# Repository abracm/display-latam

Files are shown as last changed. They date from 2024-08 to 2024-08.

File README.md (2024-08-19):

# display-latam
ESP32-based project to make a display for speedcubing timers.

We seek to create an alternative to commercially available displays which is cheaper, lighter,open-source, repairable, and sustainable.

## How to contribute

Take a look at the open issues on the repository to see how you can contribute. Open an issue for a request or suggestion. You can also send an email for contato@abracm.org.br for enquries, contributions, feedback, etc.

The language of the project is English to make it more accesible worldwide.

Please stick to the following best practices when contributing to this project:
- Open a new branch and a pull request (PR) whenever you want to change the code or documentation
- Make sure to provide enough details about the changes in your PR so other contributors can easily understand them  
- Always wait for at least one approving review before merging the PR

Currently, the code is functional, but the documentation needs work, which makes it hard for communities to build their own version. The work plan is on the short medium term is:
1. gather ideas and contributions for an Alpha release
2. incorporate pull requests, contributions which are a short term priority
3. prepare documentation, tutorials for the release of the Alpha version 
4. release the Alpha version, make easily available for communities to build and test out - can we do it by the end of August/start of September?
5. work on improvements to the Alpha version, receive feedback from users
6. create hardware specifications for a 1.0 version release (make hardware investments future proof)
7. release 1.0 version of project, make sure future code updates are backwards compatible with the hardware

## Features

TODO 
add video demo

## Libraries setup
From Libs.zip, extrac Libs folder and copy it's contents to your Arduino/Libraries directory.

## Software Installation guide
Software Installation guide:

1. Install the Arduino IDE software from https://www.arduino.cc/en/software 
2. It should create a folder named “Arduino” in Documents, you want to create 2 folders, “display-latam”, and “Libraries”.
3. Download the Libs.zip file from the GitHub, extract the zip file, and then place all of the folders in the zip file to the “Libraries” folder.

4. Place the “display-latam.ino”, “xantofont.cpp”, and “xantofont.h” files in the “display_latam folder.

5. Click on the display-latam.ino file to open it up in Arduino IDE. 
6. Connect your board to your computer with USB, the official Arduino website has more detailed instructions on this. I actually had a lot of trouble with this initially, my solution was to just try every USB port until one worked. https://support.arduino.cc/hc/en-us/articles/4406856349970-Select-board-and-port-in-Arduino-IDE 
7. Press the upload button and wait for it to upload. You also need to use a USB cable that is capable of transmitting data (some USB cables have power only) or it will not be able to upload. 



8. It should finish uploading successfully and the console should look like this when it is finished. The display should be ready for usage now.


## installation, how to build

TODO 

Draft preview of the project (using the acrylic covers)
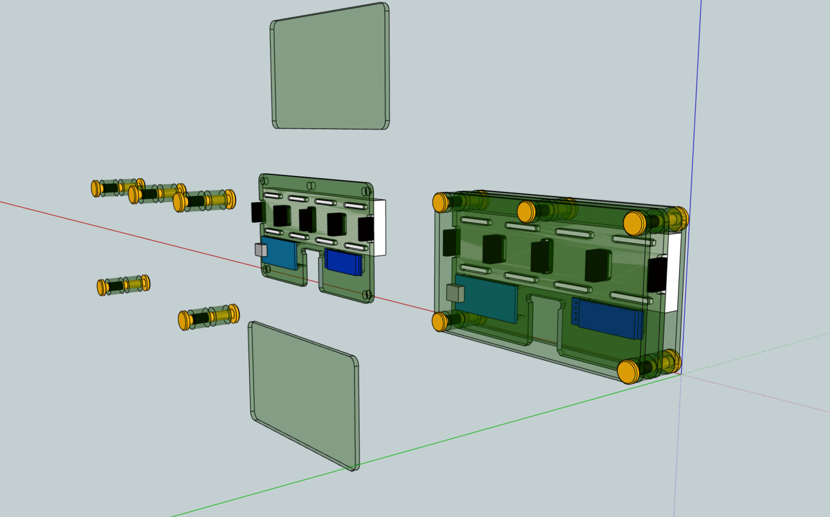
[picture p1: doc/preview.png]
draft_preview


Schematics for the ESP32 C3 mini are as follows:

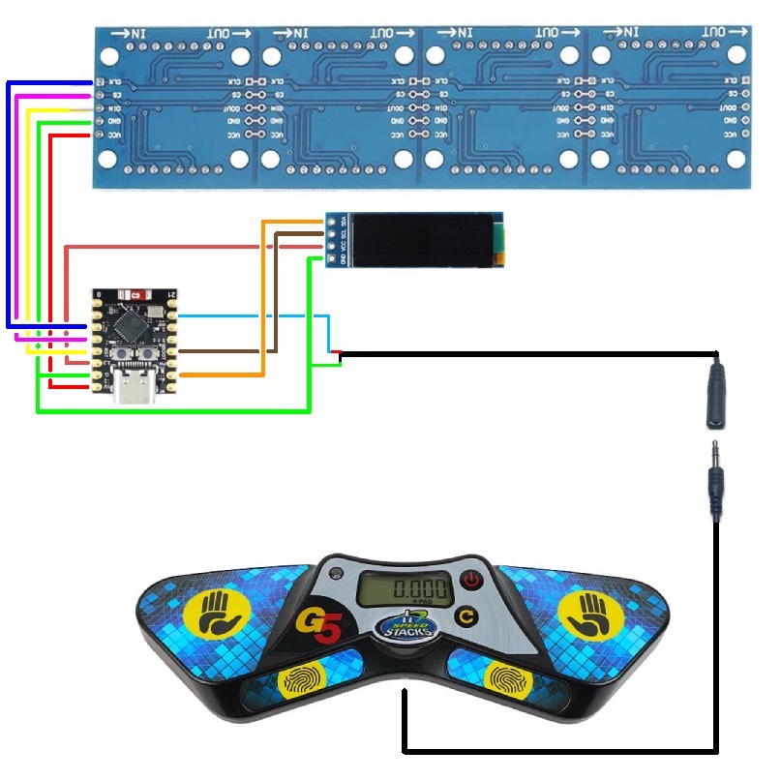
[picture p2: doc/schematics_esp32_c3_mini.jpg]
schematics_esp32_c3_mini


Schematics for the ESP32 S2 are also available at `doc/schematics_esp32_s2.jpg`
### Parts list

- ESP32 C3 mini (you might be able to use other ESP32s or Arduinos with code changes, testing needed)
- 4 in 1 MAX7219 LED display matrix
- 0.91” OLED display
- 3.5mm female jack to bare wire with 2 pole
- 3.5mm to 2.5mm data cable (to connect to the timer)
- wires and solder

Two alternatives for encasing the hardware: 

| Materials/type | Details |
| --- | --- |
| <ul><li>3mm polycarbonate sheet</li><li>Chicago screws that are 25mm long and 5mm in diameter</li><li>Spacers of 5mm in diameter with a length according to the LED matrix you have. If the display has sockets, you need spacers four 7mm long spacers and four 10mm long ones. If the display is soldered, you need eight spacers with a length of 8.5mm.</li><li>tint for contrast</li></ul> | cutout for CNC available on `doc/acrylic-cover.skp`, see `doc/prototype_demo.skp` for demo on how to build |
| 3D printed case | draft design available on `doc/draft_case.stl` (WIP) |

For power, you could use:
- Standard USBC 5v chargers plugged to a power source
- Power banks, e.g. made using 18650 batteries and a battery case (this is usually cheaper than buying a commercial power bank)

For the display stand, you could use the 3D-printed stand available on `doc/stand.stl`.

Current estimates for the cost of the materials for a display are of around USD ~20 (buying supplies off China e.g. Aliexpress).

## Contributors

We are specially greatful to Fabio Seiji Massui [2013MASS01](https://www.worldcubeassociation.org/persons/2013MASS01) for kicking off this project and inspiring us to pursue the goal of developing an open-source and cheap alternative to commercial displays.

Other contributors include:
- jayanth-rajakumar: Original [ledmat](https://github.com/jayanth-rajakumar/ledmat) project
- Cady Shields: 3D-printed display stand design
- Alex Maass: 3D-printed case design

## Speedstacks timer signal protocol

The Speedstacks timers send a digital audio signal thorugh the data port ([example](https://imgur.com/mRPrlxn)). This is a guide how on to interpret the signal.

The timer sends the signal with a fixed rate of 1200 bits per second (check if this is correct and consistent across all timer generations). It sends a packet that are 90 or 100 bytes long to convey a single time to be displayed.

### Idle values

The bitstream user a standard idle value (0 or 1) to inform when a byte or a packet ended. The idle value varies across timer generations (see section below on timer generations).

Each byte is proceeded by a non-idle value, to show that the byte has begun, and followed by an idle value, to show that it has ended.

Gen 3
*example of a Gen 3 timer bitstream- the idle value is 1*

Gen 4
*example of a Gen 4 timer bitstream- the idle value is 0*

Each packet is separated by an unspecificed number of idle values (check if we can tell an exact amount and if it is consistent across timers). Therefore, to check if a packet has ended, you just need to check if you can read ten or more equal values in a row, as that couldn't happen if a byte was being transmitted.

### Packets

A time to be displayed is sent as a packet that can be 9 or 10 bytes long. The lenght of the packet is determined by the timer generation (see section below on timer generations).

Because of the non-idle value and idle value that go before and after each byte, the bytes take 10 bits to be transmitted, and the packet lenghts are therefore 90 or 100 bits.

Here is an example of a full packet extracted from a Gen 3 timer that will use to break down what each byte means. **TODO**

Notice that this packet it 10 bytes long and uses 1 as its idle value.

These are what each byte consists of:

#### byte 1: state of the timer

The first byte is an ASCII code for one of the following letters, which represent the state the timer is in:

- "L" (Left hand on timer)
- "R" (Right hand on timer)
- "C" (Both hands on timer)
- "A" (Ready to start)
- "I" (Reset)
- "S" (Stopped)
- " " (Running and no hands on sensor)

#### byte 2-6 or 2-7: time itself

These are the bytes that convey the time information. Byte 7 may or may not be a part of this depending on the timer generation (see section below on timer generations).

Here is the breakdown on byte-by-byte:
- 2: minutes
- 3: tens of seconds
- 4: units of seconds
- 5: tenths of a second
- 6: hundreths of a second
- 7 (if in use): thousands of a second (check - if 7th byte no used to convey time information, does timer simply not transmit thousands of a second?)

The byte represents the ASCII code for the digit, which is the digit + 48

#### 3rd to last byte: checksum

This byte is a checksum of the previous bytes (2-6 or 2-7), to ensure the reading is correct.

It it the sum of the values (not the ASCII codes) of all digits + 64.

#### 2nd to last and last bytes: unnecessary line breaks?

These bytes are the ASCII codes for \n (newline) and \r (carriage return). Is this just useless?

### Processing a byte

After reading the 10 bits necessary for a byte (non-idle value + byte + idle value), you must first discard the 1st and the last bits of the byte.

Then, you must place the bits in reverse order. E.g. (11001001 becomes 10010011)

Finally, the bits must be inverted to arrive at the final byte (10010011 becomes 01101100). *do timers with a 0 idle value also need to be inverted?*

### Example of interpreting a packet from start to finish

WIP

### Speedstacks timer generations

#### Generation 3
Gen 3
- Packet length: 10 bytes
- Idle value: 1

#### Generation 4
Gen 4
- Packet length: 9 bytes (dobule check)
- Idle value: 0 (double check)

#### Generation 5
Gen 5
- Packet length: need to check
- Idle value: 1 (double check)

*can we easily support other non-speedstacks timers? testing needed*

### Useful sources

- Odder's Stacktimer Signal Processor [link](https://github.com/Kubiverse/StackmatSignalProcessor): reference on how to process the stackmat signal bitstream (for Gen 4 timers)
- JFly's [explanation](https://www.jflei.com/2014/08/21/dialup-stackmat/) on the speedstacks timer signal and reading it in a phone
- freundTech's [explanation](https://old.reddit.com/r/Cubers/comments/64czya/wip_stackmat_timer_support_for_twistytimer_app/dg19s4y/) on what the speedstacks timer signal bitstream is composed of
- Dan Smith [testing](https://youtu.be/1QEm99bT8WQ?si=v6V7CJI6A0WZBTTA) what causes reset issues in Gen 5 timers
- Coding [experiments](https://forum.arduino.cc/t/display-for-stackmat-timer/946502) on forum
- [Wiring](https://lastminuteengineers.com/max7219-dot-matrix-arduino-tutorial/) a MAX7219 LED Dot Matrix
- Getting [started](https://www.circuitgeeks.com/arduino-max7219-led-matrix-display/) with MD Parola
- Old stackmat display [project](https://web.archive.org/web/20100820185842/http://hackvalue.de:80/hv_atmel_stackmat)

#### Migrating an Arduino board to a standalone microcontroller on a breadboard

- https://docs.arduino.cc/built-in-examples/arduino-isp/ArduinoToBreadboard
- https://www.martyncurrey.com/arduino-atmega-328p-fuse-settings/
- https://www.instructables.com/Configure-Arduino-IDE-for-Atmega-328P-to-Use-8MHz-/
- https://www.instructables.com/USBASP-Bootloading-a-ATMega328p-with-a-8mhZ-intern/

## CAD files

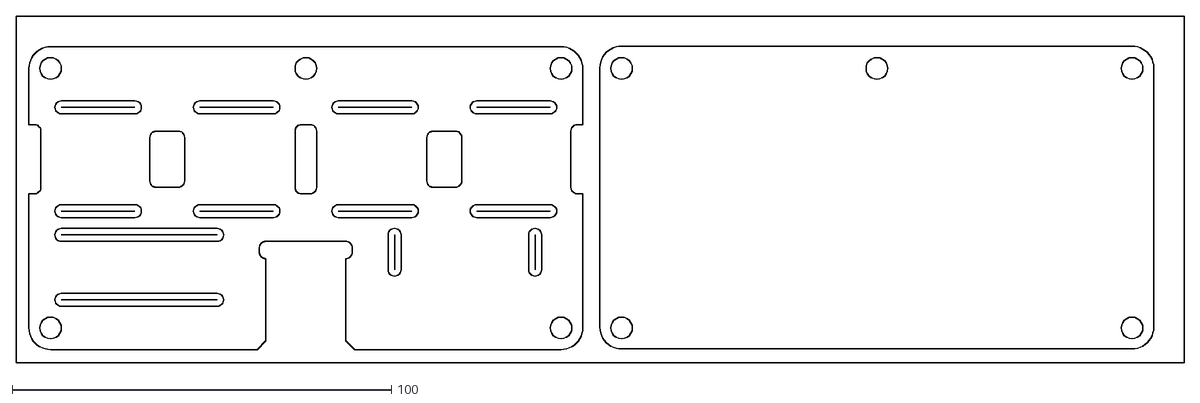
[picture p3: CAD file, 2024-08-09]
doc/AcrylicCover.dxf
308.2 x 91.3

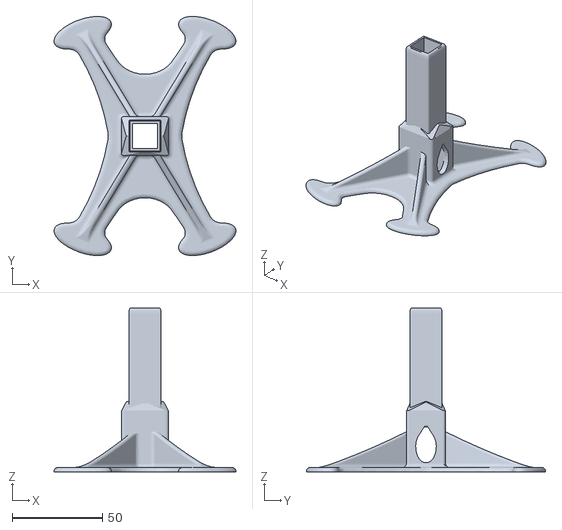
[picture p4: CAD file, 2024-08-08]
doc/stand.stl
101.1 x 132.8 x 91.0

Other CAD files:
doc/acrylic-cover.skp
doc/prototype_demo.skp

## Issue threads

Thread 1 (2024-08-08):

Decide on a better name for the project

mirandapedro, 2024-08-08:
We want a better name that:
- is more unique, marketable
- reflects the Latin American identity and origin
- is preferably in Portuguese and Spanish

Suggestions we have received so far:
- Algo en español/portugués podría ser interesante para indicar el origen
- "Números" quizás jajaj o alguna cosa así que sea igual en ambos idiomas
- display purtanol
- all i can think that is common for all latin america is the passion for futebol

SeijiMassui, 2024-08-21:
My suggestion is Megatherium

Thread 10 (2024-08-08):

Improve installation guide and build guide

mirandapedro, 2024-08-08:
Ideally, we'd have both the usual technical documentation, but also a very basic how-to guide (if possible, even a video), teaching how to build the project, so that it is as accessible as possible for communities, regardless of their level of technical expertise.

mirandapedro, 2024-08-09:
Should we recommend a specific version of an ESP32/arduino as a default for the project or can we make the project and code version neutral?

alexmaasswca, 2024-08-09:
I think we should stick with the C3because the acrylic case is designed for that, the boards seem to be roughly all about a few dollars on aliexpress for me so I don't see any major price differences there.

I think we should try to get the C3 working first and perfected and then add in support for different boards.

mirandapedro, 2024-08-09:
Just to note the specific version of the ESP32 C3 mini we used in our first batch of display is the ESP32-C3FH4. I don't believe any of the differences between the versions of the ESP32 C3 mini impact our project, but it's worth noting for future testing and documentation.

soyrandom1, 2024-08-17:
Code should work with most arduino or esp versions.
In some cases used pins might change depending on the board used, but it's extremely easy to modify in code.

mirandapedro, 2024-08-17:
@soyrandom1 do you believe the code is ready for an Alpha release (after merging your PR)?

If so, the only thing holding us back would be the documentation/tutorial.

My hope was to have an alpha version ready as soon as possible to make the first prototype available to interested communities. Also, a first release might also attract the interest of additional contributors.

soyrandom1, 2024-08-19:
Solved #19

Closed 2024-08-19.

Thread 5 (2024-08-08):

Prevent the Gen 5 timer from switching on and off the time displayed after an attempt

mirandapedro, 2024-08-08:
- the Gen 5 timer has an annoying feature that, when in 2-pad mode, it switches off and on three times after the timer is stopped, which is reproduced on the display, we should try to avoid this behaviour

I have the impression that the current version of the code already prevents this, we need to check

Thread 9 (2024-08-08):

Improve the schematics in the README

mirandapedro, 2024-08-08:

mirandapedro, 2024-08-17:
Fixed by 3844d9cc04f159badeeef381240765e3ebc82951

Closed 2024-08-17.

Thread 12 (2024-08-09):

Libraries missing

alexmaasswca, 2024-08-09:
I had a lot of trouble installing arduino libraries with the jayanth github. I think it is problematic to just simply say "download this library from this other github" because the libraries can change, this actually led to an issue with jayanth's project because he had to reupload an older version of the libraries so it would work for other people.

This is the same case here, for example running the program gets me this error that simply says that the Adafruit.h library is not there so I think it would be best to have a UsedLibraries folder on the github here and place every library needed in that folder, so it'll always work and be very easy to download multiple libraries without having to worry about the libraries being updated.

I'll be down to write a guide on how to install the whole thing once the libraries are posted in a folder here.

soyrandom1, 2024-08-17:
Uploaded all libraries [here](https://github.com/abracm/display-latam/blob/main/Libs.zip)

Closed 2024-08-17.

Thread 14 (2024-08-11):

Alternative to the 3D-printed stand

mirandapedro, 2024-08-11:
Can we think of a better alternative to the 3D-printed stand? Is it needed?

Fabio Seiji experimented with aluminium extrusions (see below). Alex Maass also suggested using them.

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

This contraption would attach vertically to a table. The yellow parts were supposed to act as clamps to hold the stand up. In practice, it didn't work very well.

alexmaasswca, 2024-08-13:
https://www.aliexpress.us/item/3256807085443535.html this looks decent, I just ordered one to test out

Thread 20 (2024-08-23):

LED Matrix increases in brightness several seconds after timer with 0.00 is turned off

alexmaasswca, 2024-08-23:
The LED Matrix increases in brightness several seconds after timer with 0.00 is turned off, I can replicate with a video if necessary. This is a pretty minor issue, I don't see the harm in this besides unnecessary battery usage.

soyrandom1, 2024-08-23:
Fixed here https://github.com/abracm/display-latam/pull/21

Closed 2024-08-23.

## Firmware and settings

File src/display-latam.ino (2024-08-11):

#include <Arduino.h>

//OLED Display Libraries
#include <Adafruit_GFX.h>
#include <Adafruit_SSD1306.h>

//Libraries for LED Matrix
#include <MD_Parola.h>
#include <MD_MAX72xx.h>

//Communication Libaries
#include <SPI.h>
#include <Wire.h>
#include <SoftwareSerial.h>

//StackmatTimer Library
#include <StackmatTimer.h>

//OLED Font
#include <Fonts/FreeSans18pt7b.h>

//Define LED Matrix and SPI communication ports/pins
#define MAX_DEVICES 4
#define CLK_PIN 2
#define DATA_PIN 4
#define CS_PIN 3
#define HARDWARE_TYPE MD_MAX72XX::FC16_HW

//Define I2C ports/pins for OLED communication
#define SDA_PIN 6
#define SCL_PIN 8

#define SCREEN_WIDTH 128  // OLED display length in pixels
#define SCREEN_HEIGHT 32  // OLED display height in pixels

#define OLED_RESET -1
#define OLED_ADDRESS 0x3c

//#define led_ON 15 // S2 Mini onboard LED

MD_Parola P = MD_Parola(HARDWARE_TYPE, DATA_PIN, CLK_PIN, CS_PIN, MAX_DEVICES);

Adafruit_SSD1306 oled(SCREEN_WIDTH, SCREEN_HEIGHT, &Wire, OLED_RESET);

//Font for LED Matrix
MD_MAX72XX::fontType_t xantofont[] PROGMEM = {
  0,                              // 0 - 'Empty Cell'
  5, 62, 91, 79, 91, 62,          // 1 - 'Sad Smiley'
  5, 62, 107, 79, 107, 62,        // 2 - 'Happy Smiley'
  5, 28, 62, 124, 62, 28,         // 3 - 'Heart'
  5, 24, 60, 126, 60, 24,         // 4 - 'Diamond'
  5, 28, 87, 125, 87, 28,         // 5 - 'Clubs'
  5, 28, 94, 127, 94, 28,         // 6 - 'Spades'
  4, 0, 24, 60, 24,               // 7 - 'Bullet Point'
  5, 255, 231, 195, 231, 255,     // 8 - 'Rev Bullet Point'
  4, 0, 24, 36, 24,               // 9 - 'Hollow Bullet Point'
  5, 255, 231, 219, 231, 255,     // 10 - 'Rev Hollow BP'
  5, 48, 72, 58, 6, 14,           // 11 - 'Male'
  5, 38, 41, 121, 41, 38,         // 12 - 'Female'
  5, 64, 127, 5, 5, 7,            // 13 - 'Music Note 1'
  5, 64, 127, 5, 37, 63,          // 14 - 'Music Note 2'
  5, 90, 60, 231, 60, 90,         // 15 - 'Snowflake'
  5, 127, 62, 28, 28, 8,          // 16 - 'Right Pointer'
  5, 8, 28, 28, 62, 127,          // 17 - 'Left Pointer'
  5, 20, 34, 127, 34, 20,         // 18 - 'UpDown Arrows'
  5, 95, 95, 0, 95, 95,           // 19 - 'Double Exclamation'
  5, 6, 9, 127, 1, 127,           // 20 - 'Paragraph Mark'
  4, 102, 137, 149, 106,          // 21 - 'Section Mark'
  5, 96, 96, 96, 96, 96,          // 22 - 'Double Underline'
  5, 148, 162, 255, 162, 148,     // 23 - 'UpDown Underlined'
  5, 8, 4, 126, 4, 8,             // 24 - 'Up Arrow'
  5, 16, 32, 126, 32, 16,         // 25 - 'Down Arrow'
  5, 8, 8, 42, 28, 8,             // 26 - 'Right Arrow'
  5, 8, 28, 42, 8, 8,             // 27 - 'Left Arrow'
  5, 30, 16, 16, 16, 16,          // 28 - 'Angled'
  5, 12, 30, 12, 30, 12,          // 29 - 'Squashed #'
  5, 48, 56, 62, 56, 48,          // 30 - 'Up Pointer'
  5, 6, 14, 62, 14, 6,            // 31 - 'Down Pointer'
  2, 0, 0,                        // 32 - 'Space'
  1, 95,                          // 33 - '!'
  3, 7, 0, 7,                     // 34 - '"'
  5, 20, 127, 20, 127, 20,        // 35 - '#'
  5, 36, 42, 127, 42, 18,         // 36 - '$'
  5, 35, 19, 8, 100, 98,          // 37 - '%'
  5, 54, 73, 86, 32, 80,          // 38 - '&'
  3, 8, 7, 3,                     // 39 - '''
  3, 28, 34, 65,                  // 40 - '('
  3, 65, 34, 28,                  // 41 - ')'
  5, 42, 28, 127, 28, 42,         // 42 - '*'
  5, 8, 8, 62, 8, 8,              // 43 - '+'
  3, 128, 112, 48,                // 44 - ','
  6, 0, 8, 8, 8, 8, 8,            // 45 - '-'
  1, 64,                          // 2, 964, 96,    // 46 - '.'
  5, 32, 16, 8, 4, 2,             // 47 - '/'
  5, 126, 129, 129, 126, 0,       // 6, 0, 126, 129, 129, 129, 126,    // 48 - '0'
  5, 130, 255, 128, 0, 0,         // 6, 0, 0, 130, 255, 128,0,   // 49 - '1'
  5, 226, 145, 137, 134, 0,       // 6, 0, 130, 193, 161, 145, 142,    // 50 - '2'
  5, 66, 137, 137, 118, 0,        // 6, 0, 66, 129, 137, 137, 118,   // 51 - '3'
  5, 24, 20, 18, 255, 0,          // 6, 0, 48, 40, 36, 34, 255,    // 52 - '4'
  5, 79, 137, 137, 113, 0,        // 6, 0, 79, 137, 137, 137, 113,   // 53 - '5'
  5, 126, 137, 137, 114, 0,       // 6, 0, 126, 137, 137, 137, 114,    // 54 - '6'
  5, 225, 17, 9, 7, 0,            // 6, 0, 1, 225, 17, 9, 7,   // 55 - '7'
  5, 118, 137, 137, 118, 0,       // 6, 0, 118, 137, 137, 137, 118,    // 56 - '8'
  5, 78, 145, 145, 126, 0,        // 6, 0, 78, 145, 145, 145, 126,   // 57 - '9'
  1, 68,                          // 1, 36,    // 58 - ':'
  2, 128, 104,                    // 59 - ';'
  4, 8, 20, 34, 65,               // 60 - '<'
  5, 20, 20, 20, 20, 20,          // 61 - '='
  4, 65, 34, 20, 8,               // 62 - '>'
  5, 2, 1, 89, 9, 6,              // 63 - '?'
  5, 62, 65, 93, 89, 78,          // 64 - '@'
  5, 124, 18, 17, 18, 124,        // 65 - 'A'
  5, 127, 73, 73, 73, 54,         // 66 - 'B'
  5, 62, 65, 65, 65, 34,          // 67 - 'C'
  5, 127, 65, 65, 65, 62,         // 68 - 'D'
  5, 127, 73, 73, 73, 65,         // 69 - 'E'
  5, 127, 9, 9, 9, 1,             // 70 - 'F'
  5, 62, 65, 65, 81, 115,         // 71 - 'G'
  5, 127, 8, 8, 8, 127,           // 72 - 'H'
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
  5, 60, 38, 35, 38, 60,          // 127 - 'Hollow Up Arrow'
  5, 30, 161, 161, 97, 18,        // 128 - 'C sedilla'
  5, 56, 66, 64, 34, 120,         // 129 - 'u umlaut'
  5, 56, 84, 84, 85, 89,          // 130 - 'e acute'
  5, 33, 85, 85, 121, 65,         // 131 - 'a accent'
  5, 33, 84, 84, 120, 65,         // 132 - 'a umlaut'
  5, 33, 85, 84, 120, 64,         // 133 - 'a grave'
  5, 32, 84, 85, 121, 64,         // 134 - 'a acute'
  5, 24, 60, 164, 228, 36,        // 135 - 'c sedilla'
  5, 57, 85, 85, 85, 89,          // 136 - 'e accent'
  5, 56, 85, 84, 85, 88,          // 137 - 'e umlaut'
  5, 57, 85, 84, 84, 88,          // 138 - 'e grave'
  3, 69, 124, 65,                 // 139 - 'i umlaut'
  4, 2, 69, 125, 66,              // 140 - 'i hat'
  4, 1, 69, 124, 64,              // 141 - 'i grave'
  5, 240, 41, 36, 41, 240,        // 142 - 'A umlaut'
  5, 240, 40, 37, 40, 240,        // 143 - 'A dot'
  4, 124, 84, 85, 69,             // 144 - 'E grave'
  7, 32, 84, 84, 124, 84, 84, 8,  // 145 - 'ae'
  6, 124, 10, 9, 127, 73, 73,     // 146 - 'AE'
  5, 50, 73, 73, 73, 50,          // 147 - 'o hat'
  5, 48, 74, 72, 74, 48,          // 148 - 'o umlaut'
  5, 50, 74, 72, 72, 48,          // 149 - 'o grave'
  5, 58, 65, 65, 33, 122,         // 150 - 'u hat'
  5, 58, 66, 64, 32, 120,         // 151 - 'u grave'
  4, 157, 160, 160, 125,          // 152 - 'y umlaut'
  5, 56, 69, 68, 69, 56,          // 153 - 'O umlaut'
  5, 60, 65, 64, 65, 60,          // 154 - 'U umlaut'
  5, 60, 36, 255, 36, 36,         // 155 - 'Cents'
  5, 72, 126, 73, 67, 102,        // 156 - 'Pounds'
  5, 43, 47, 252, 47, 43,         // 157 - 'Yen'
  5, 255, 9, 41, 246, 32,         // 158 - 'R +'
  5, 192, 136, 126, 9, 3,         // 159 - 'f notation'
  5, 32, 84, 84, 121, 65,         // 160 - 'a acute'
  3, 68, 125, 65,                 // 161 - 'i acute'
  5, 48, 72, 72, 74, 50,          // 162 - 'o acute'
  5, 56, 64, 64, 34, 122,         // 163 - 'u acute'
  4, 122, 10, 10, 114,            // 164 - 'n accent'
  5, 125, 13, 25, 49, 125,        // 165 - 'N accent'
  5, 38, 41, 41, 47, 40,          // 166
  5, 38, 41, 41, 41, 38,          // 167
  5, 48, 72, 77, 64, 32,          // 168 - 'Inverted ?'
  5, 56, 8, 8, 8, 8,              // 169
  5, 8, 8, 8, 8, 56,              // 170
  5, 47, 16, 200, 172, 186,       // 171 - '1/2'
  5, 47, 16, 40, 52, 250,         // 172 - '1/4'
  1, 123,                         // 173 - '| split'
  5, 8, 20, 42, 20, 34,           // 174 - '<<'
  5, 34, 20, 42, 20, 8,           // 175 - '>>'
  5, 170, 0, 85, 0, 170,          // 176 - '30% shading'
  5, 170, 85, 170, 85, 170,       // 177 - '50% shading'
  5, 0, 0, 0, 0, 255,             // 178 - 'Right side'
  5, 16, 16, 16, 16, 255,         // 179 - 'Right T'
  5, 20, 20, 20, 20, 255,         // 180 - 'Right T double H'
  5, 16, 16, 255, 0, 255,         // 181 - 'Right T double V'
  5, 16, 16, 240, 16, 240,        // 182 - 'Top Right double V'
  5, 20, 20, 20, 20, 252,         // 183 - 'Top Right double H'
  5, 20, 20, 247, 0, 255,         // 184 - 'Right T double all'
  5, 0, 0, 255, 0, 255,           // 185 - 'Right side double'
  5, 20, 20, 244, 4, 252,         // 186 - 'Top Right double'
  5, 20, 20, 23, 16, 31,          // 187 - 'Bot Right double'
  5, 16, 16, 31, 16, 31,          // 188 - 'Bot Right double V'
  5, 20, 20, 20, 20, 31,          // 189 - 'Bot Right double H'
  5, 16, 16, 16, 16, 240,         // 190 - 'Top Right'
  5, 0, 0, 0, 31, 16,             // 191 - 'Bot Left'
  5, 16, 16, 16, 31, 16,          // 192 - 'Bot T'
  5, 16, 16, 16, 240, 16,         // 193 - 'Top T'
  5, 0, 0, 0, 255, 16,            // 194 - 'Left T'
  5, 16, 16, 16, 16, 16,          // 195 - 'Top side'
  5, 16, 16, 16, 255, 16,         // 196 - 'Center +'
  5, 0, 0, 0, 255, 20,            // 197 - 'Left side double H'
  5, 0, 0, 255, 0, 255,           // 198 - 'Left side double'
  5, 0, 0, 31, 16, 23,            // 199 - 'Bot Left double V'
  5, 0, 0, 252, 4, 244,           // 200 - 'Top Left double V'
  5, 20, 20, 23, 16, 23,          // 201 - 'Bot T double'
  5, 20, 20, 244, 4, 244,         // 202 - 'Top T double'
  5, 0, 0, 255, 0, 247,           // 203 - 'Left Side double spl'
  5, 20, 20, 20, 20, 20,          // 204 - 'Center double'
  5, 20, 20, 247, 0, 247,         // 205 - 'Center + double'
  5, 20, 20, 20, 23, 20,          // 206 - 'Bot T double H'
  5, 16, 16, 31, 16, 31,          // 207 - 'Bot Right double V'
  5, 20, 20, 20, 244, 20,         // 208 - 'Top T double H'
  5, 16, 16, 240, 16, 240,        // 209 - 'Top Right double V'
  5, 0, 0, 31, 16, 31,            // 210 - 'Bot Left double V'
  5, 0, 0, 0, 31, 20,             // 211 - 'Bot Right double H'
  5, 0, 0, 0, 252, 20,            // 212 - 'Top Right double H'
  5, 0, 0, 240, 16, 240,          // 213 - 'Top Right double V'
  5, 16, 16, 255, 16, 255,        // 214 - 'Center + double V'
  5, 20, 20, 20, 255, 20,         // 215 - 'Center + double H'
  5, 16, 16, 16, 16, 31,          // 216 - 'Bot Right'
  5, 0, 0, 0, 240, 16,            // 217 - 'Top Left'
  5, 255, 255, 255, 255, 255,     // 218 - 'Full Block'
  5, 240, 240, 240, 240, 240,     // 219 - 'Half Block Bottom'
  3, 255, 255, 255,               // 220 - 'Half Block LHS'
  5, 0, 0, 0, 255, 255,           // 221 - 'Half Block RHS'
  5, 15, 15, 15, 15, 15,          // 222 - 'Half Block Top'
  5, 56, 68, 68, 56, 68,          // 223 - 'Alpha'
  5, 124, 42, 42, 62, 20,         // 224 - 'Beta'
  5, 126, 2, 2, 6, 6,             // 225 - 'Gamma'
  5, 2, 126, 2, 126, 2,           // 226 - 'Pi'
  5, 99, 85, 73, 65, 99,          // 227 - 'Sigma'
  5, 56, 68, 68, 60, 4,           // 228 - 'Theta'
  5, 64, 126, 32, 30, 32,         // 229 - 'mu'
  5, 6, 2, 126, 2, 2,             // 230 - 'Tau'
  5, 153, 165, 231, 165, 153,     // 231
  5, 28, 42, 73, 42, 28,          // 232
  5, 76, 114, 1, 114, 76,         // 233
  5, 48, 74, 77, 77, 48,          // 234
  5, 48, 72, 120, 72, 48,         // 235
  5, 188, 98, 90, 70, 61,         // 236 - 'Zero Slashed'
  4, 62, 73, 73, 73,              // 237
  5, 126, 1, 1, 1, 126,           // 238
  5, 42, 42, 42, 42, 42,          // 239 - '3 Bar Equals'
  5, 68, 68, 95, 68, 68,          // 240 - '+/-'
  5, 64, 81, 74, 68, 64,          // 241 - '>='
  5, 64, 68, 74, 81, 64,          // 242 - '<='
  5, 0, 0, 255, 1, 3,             // 243 - 'Top of Integral'
  3, 224, 128, 255,               // 244 - 'Bot of Integral'
  5, 8, 8, 107, 107, 8,           // 245 - 'Divide'
  5, 54, 18, 54, 36, 54,          // 246 - 'Wavy ='
  5, 6, 15, 9, 15, 6,             // 247 - 'Degree'
  4, 0, 0, 24, 24,                // 248 - 'Math Product'
  4, 0, 0, 16, 16,                // 249 - 'Short Dash'
  5, 48, 64, 255, 1, 1,           // 250 - 'Square Root'
  5, 0, 31, 1, 1, 30,             // 251 - 'Superscript n'
  5, 0, 25, 29, 23, 18,           // 252 - 'Superscript 2'
  5, 0, 60, 60, 60, 60,           // 253 - 'Centered Square'
  5, 255, 129, 129, 129, 255,     // 254 - 'Full Frame'
  5, 255, 255, 255, 255, 255,     // 255 - 'Full Block'
};

char tempo[7];   // Declare variable "time" with 7 characters M:SS.CC
int minuto;
int segundos;
int centesimos;

// *****LIB STACKMAT

#define RX_PIN 20  // Define timer signal input pin
SoftwareSerial mySerial(RX_PIN, 255, true);

// Declare 'chronometer' instance in StackmatTimer
StackmatTimer cronometro(&mySerial);
StackmatTimerState lastState;

void setup() {

//  pinMode(led_ON, OUTPUT);

  Serial.begin(19200);

  P.begin();             //Initialize LED Matrix
  P.setIntensity(0);     //Sets the initial brightness to 0
  P.setFont(xantofont);  //Set font to the xantofont defined above

  Wire.begin(SDA_PIN, SCL_PIN);  //Initialize the I2C pins
  oled.begin();                  //Initializes OLED

  // SSD1306_SWITCHCAPVCC = generate display voltage from 3.3V internally
  if (!oled.begin(SSD1306_SWITCHCAPVCC, OLED_ADDRESS)) {
    Serial.println(F("SSD1306 allocation failed"));
    while (true)
      ;  // Don't proceed, loop forever
  }

  delay(100);

  oled.clearDisplay();
  oled.setTextColor(WHITE);


  // Start serial, Baud rate is set to 1200
  mySerial.begin(STACKMAT_TIMER_BAUD_RATE);
}

void loop() {
//  digitalWrite(led_ON, HIGH); //Turning on the board's LED to show that it is on

  // Update the cronometro, this will update all the fields on the cronometro like State and Time.
  cronometro.Update();


  // assume cronometro is disconected
  if (!cronometro.IsConnected()) {
    Serial.println("Cronômetro não está conectado");  //para monitorar

    P.print("");          // Display empty text on LED matrix

    // Sending to OLED
    oled.clearDisplay();  // Clearing internal memory
    oled.display();
    delay(10);
  }

  // Timer state is changing
  if (cronometro.GetState() != lastState) {
    switch (cronometro.GetState()) {
      case ST_Stopped:
        Serial.printf("SEU TEMPO FOI DE %i:%02i.%03i!\n", cronometro.  // para monitorar
        GetDisplayMinutes(),
        cronometro.GetDisplaySeconds(), cronometro.GetDisplayMilliseconds());
        minuto = cronometro.GetInterpolatedDisplayMinutes();
        segundos = cronometro.GetInterpolatedDisplaySeconds();
        centesimos = cronometro.GetInterpolatedDisplayMilliseconds();
        centesimos = (centesimos / 10);  //Eliminando terceira casa
        sprintf(tempo, "%01d:%02d.%02d", minuto, segundos, centesimos);

        P.setIntensity(8);     //Set brightness to 8 when timer stops
        P.print(tempo);  //Display time on LED Matrix

        oled.clearDisplay();  // Clearing internal Memory
        oled.setFont(&FreeSans18pt7b);
        oled.setTextSize(1);
        oled.setCursor(10, 30);
        oled.print(tempo);
        oled.display();
        break;
      case ST_Reset:
        // resetting variables when the timer is zero
        minuto = 0;
        segundos = 0;
        centesimos = 0;
        sprintf(tempo, "%01d:%02d.%02d", minuto, segundos, centesimos);
        Serial.println("cronometro está zerado");  //para monitorar

        P.setIntensity(0);      //Set brightness to 0 when timer reset
        P.print(tempo);  //Apresentando na matriz de led

        oled.clearDisplay();  // Clearing internal memory
        oled.setFont(&FreeSans18pt7b);
        oled.setTextSize(1);
        oled.setCursor(10, 30);
        oled.print("0:00.00");
        oled.display();       //Displaying on OLED
        break;
      case ST_Running:
        Serial.println("GO!");
        break;
      case ST_LeftHandOnTimer:
        Serial.println("Left hand on timer!");
        break;
      case ST_RightHandOnTimer:
        Serial.println("Right hand on timer!");
        break;
      case ST_BothHandsOnTimer:
        Serial.println("Both hands on timer!");
        break;
      case ST_ReadyToStart:
        Serial.println("Pronto!");
        P.setIntensity(2);    //Set brightness to medium when green light comes on        
        break;
      default:
        Serial.println("Unknown state!");
        Serial.println(cronometro.GetState());
        break;
    }
  }

  // Show time when timer is running
  if (cronometro.GetState() == ST_Running) {
    minuto = cronometro.GetInterpolatedDisplayMinutes();
    segundos = cronometro.GetInterpolatedDisplaySeconds();
    centesimos = cronometro.GetInterpolatedDisplayMilliseconds();
    centesimos = (centesimos / 10);          // Delete third decimal place
    sprintf(tempo, "%01d:%02d.%02d", minuto, segundos, centesimos);  // Format time data for timer
    Serial.println(tempo);          //para monitorar

    P.setIntensity(5);      //Medium brightness when timer is running
    P.print(tempo);  // Display time on LED matrix

    oled.clearDisplay();  //Clearing internal Memory
    oled.setFont(&FreeSans18pt7b);
    oled.setTextSize(1);
    oled.setCursor(10, 30);
    oled.println(tempo);
    oled.display();       // Display on OLED
  }

  lastState = cronometro.GetState();

  delay(10);
}

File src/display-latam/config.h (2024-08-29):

#ifndef CONFIG_H
#define CONFIG_H

// Define constants
#define MAX_DEVICES 4
#define CLK_PIN 2
#define DATA_PIN 4
#define CS_PIN 3
#define SDA_PIN 6
#define SCL_PIN 8
#define SCREEN_WIDTH 128
#define SCREEN_HEIGHT 32
#define OLED_RESET -1
#define OLED_ADDRESS 0x3c
#define INITIAL_BRIGHTNESS 0
#define RESET_BRIGHTNESS 0
#define RUNNING_BRIGHTNESS 5
#define STOPPED_BRIGHTNESS 8
#define RX_PIN 20

const float OLED_TEXT_SIZE = 1;
const int INITIAL_OLED_X = 10;
const int INITIAL_OLED_Y = 30;

#endif

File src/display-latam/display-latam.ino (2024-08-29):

#include <Arduino.h>
#include <Adafruit_GFX.h>
#include <Adafruit_SSD1306.h>
#include <MD_Parola.h>
#include <MD_MAX72xx.h>
#include <SPI.h>
#include <Wire.h>
#include <SoftwareSerial.h>
#include <StackmatTimer.h>
#include <Fonts/FreeSans18pt7b.h>
#include "xantofont.h"
#include "config.h"

#define HARDWARE_TYPE MD_MAX72XX::FC16_HW

MD_Parola LED_DISPLAY = MD_Parola(HARDWARE_TYPE, DATA_PIN, CLK_PIN, CS_PIN, MAX_DEVICES);
Adafruit_SSD1306 oled(SCREEN_WIDTH, SCREEN_HEIGHT, &Wire, OLED_RESET);


char display_time[7]; // Time format M:SS.CC
int minutes;
int seconds;
int centiseconds;


SoftwareSerial timerSerial(RX_PIN, 255, true);
StackmatTimer cronometro(&timerSerial);
StackmatTimerState lastState;

void setup() {
  Serial.begin(19200);

  if (!LED_DISPLAY.begin()) {
    Serial.println("LED Display initialization failed!");
    while (true);
  }
  LED_DISPLAY.setIntensity(INITIAL_BRIGHTNESS);
  LED_DISPLAY.setFont(xantofont);

  Wire.begin(SDA_PIN, SCL_PIN);
  if (!oled.begin(SSD1306_SWITCHCAPVCC, OLED_ADDRESS)) {
    Serial.println(F("SSD1306 allocation failed"));
    while (true);
  }

  oled.clearDisplay();
  oled.setTextColor(WHITE);
  timerSerial.begin(STACKMAT_TIMER_BAUD_RATE);
}

void loop() {
  cronometro.Update();

  if (!cronometro.IsConnected()) {
    Serial.println("Timer is not connected");
    clearAndUpdateOLED("0:00.00");
    LED_DISPLAY.setIntensity(RESET_BRIGHTNESS);
    LED_DISPLAY.print(display_time);
    delay(1000);
    return;
  }

  if (cronometro.GetState() != lastState) {
    handleStateChange(cronometro.GetState());
  }

  if (cronometro.GetState() == ST_Running) {
    minutes = cronometro.GetInterpolatedDisplayMinutes();
    seconds = cronometro.GetInterpolatedDisplaySeconds();
    centiseconds = cronometro.GetInterpolatedDisplayMilliseconds();
    centiseconds = (centiseconds / 10);
    sprintf(display_time, "%01d:%02d.%02d", minutes, seconds, centiseconds);
    Serial.println(display_time);

    LED_DISPLAY.setIntensity(RUNNING_BRIGHTNESS);
    LED_DISPLAY.print(display_time);

    clearAndUpdateOLED(display_time);
  }

  lastState = cronometro.GetState();
  delay(10);
}

void clearAndUpdateOLED(const char* message) {
  oled.clearDisplay();
  oled.setFont(&FreeSans18pt7b);
  oled.setTextSize(OLED_TEXT_SIZE);
  oled.setCursor(INITIAL_OLED_X, INITIAL_OLED_Y);
  oled.print(message);
  oled.display();
}

void handleStateChange(StackmatTimerState state) {
  switch (state) {
    case ST_Stopped:
      minutes = cronometro.GetInterpolatedDisplayMinutes();
      seconds = cronometro.GetInterpolatedDisplaySeconds();
      centiseconds = cronometro.GetInterpolatedDisplayMilliseconds();
      centiseconds = (centiseconds / 10);
      sprintf(display_time, "%01d:%02d.%02d", minutes, seconds, centiseconds);

      LED_DISPLAY.setIntensity(STOPPED_BRIGHTNESS);
      LED_DISPLAY.print(display_time);

      clearAndUpdateOLED(display_time);
      break;
    case ST_Reset:
      minutes = 0;
      seconds = 0;
      centiseconds = 0;
      sprintf(display_time, "%01d:%02d.%02d", minutes, seconds, centiseconds);

      LED_DISPLAY.setIntensity(RESET_BRIGHTNESS);
      LED_DISPLAY.print(display_time);

      clearAndUpdateOLED("0:00.00");
      break;
    case ST_Running:
      Serial.println("GO!");
      break;
    case ST_LeftHandOnTimer:
      Serial.println("Left hand on timer!");
      break;
    case ST_RightHandOnTimer:
      Serial.println("Right hand on timer!");
      break;
    case ST_BothHandsOnTimer:
      Serial.println("Both hands on timer!");
      break;
    case ST_ReadyToStart:
      Serial.println("Ready to start!");
      LED_DISPLAY.setIntensity(RESET_BRIGHTNESS);
      break;
    default:
      Serial.println("Unknown state!");
      Serial.println(cronometro.GetState());
      break;
  }
}

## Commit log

2024-08-08 Initial commit
    Legacy files from abracm/ledmat
2024-08-08 Remove legacy files from abracm/ledmat
    Starting over fresh
2024-08-08 Add initial project files
    [acrylic-cover.skp, stand.stl]
2024-08-09 Clarify you might be able to use other versions of ESP32s or arduinos
2024-08-09 Add files via upload (#11)
    Converted Sketchup file to a dxf file
    [AcrylicCover.dxf]
2024-08-09 Add preview of the project build using the acrylic covers
    [prototype_demo.skp]
2024-08-09 Update schematics
2024-08-09 Fix info on female 3.5mm jack
2024-08-14 Improved code readability, moved led display font to it's own header file, moved main file to display-latam folder inside SRC
2024-08-17 Improved code readability, moved led display font to it's own header file, moved main file to display-latam folder inside SRC (#15)
2024-08-23 Added config.h, fixed display intensity changes when restarted.
    [config.h, display-latam.ino]
2024-08-23 Forgot display intensity fix
    [display-latam.ino]
